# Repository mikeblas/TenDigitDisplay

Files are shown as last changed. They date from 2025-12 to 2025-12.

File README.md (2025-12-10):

Here is a project I made in the summer of 2025.

On a driving trip from Chicago back home to Seattle, I discovered [American Science and Surplus](https://sciplus.com/). Their store in Geneva, Illinois has lots of fun stuff, including some two-digit LED displays that I thought I could use to make a neat display.

The circuit in this project multiplexes the displays so they can be driven by the ESP-32. After a few iterations on the breadboard, I got boards done at [OSH Park](https://oshpark.com/) and soldered them up with through-hole parts that I mostly had in my inventory.

The web server on the ESP-32 has two endpoints: one takes a ten-digit hex string, which is a bitmap of the segments to illuminate on the display. The other takes a string of numbers to display -- they're converted from ASCII to their seven-segment representation.

I want to use the project to display some stock prices as they change. Since there's just seven segments, it's a bit crude, but something like "183.78d 1.19" means that the issue I'm tracking is at $183.78 per share, down (for "d") $1.19 per share since the last close.

Right now, all the smarts are in a Python scripts that run on a desktop computer. That script pokes at those endpoints and the ESP-32 just scans the multiplexed displays to show the last thing it was told. Eventually, the device could be standalone, though that comes with a few problems that I'll need to sort out.

Things to do:

* Make the Python script support multiple devices
* Show the DHCP-assigned IP address of the ESP-32 on the LEDs at startup
* Have the ESP-32 beacon a UDP message for automatic discovery by client scripts
* Smarter endpoints: accept characters and decimal points, for example
* Use the on-board LED to indicate stale data -- if no client has made an update in some time

And probably a few more things. But I'm also thinking about 16-segment display with 2 rows of 20 characters for a bit more fidelity ...

This repo contains these directories:

* `assets`: some pictures for the readme
* `TenDigitPCB`: a KiCAD project (including shape and footprint files) for the PCB and its components
* `TenDigitsIDF`: Visual Studio Code project for the ESP-32 IDF to implement the web server and multiplexing
* `TenDigitQuoter`: A Python project (for PyCharm) that shows quotes for a stock from the Yahoo! Finance API

Here are some pictures:

Front view of populated PCB

Reverse view of bare PCB

Quote being displayed

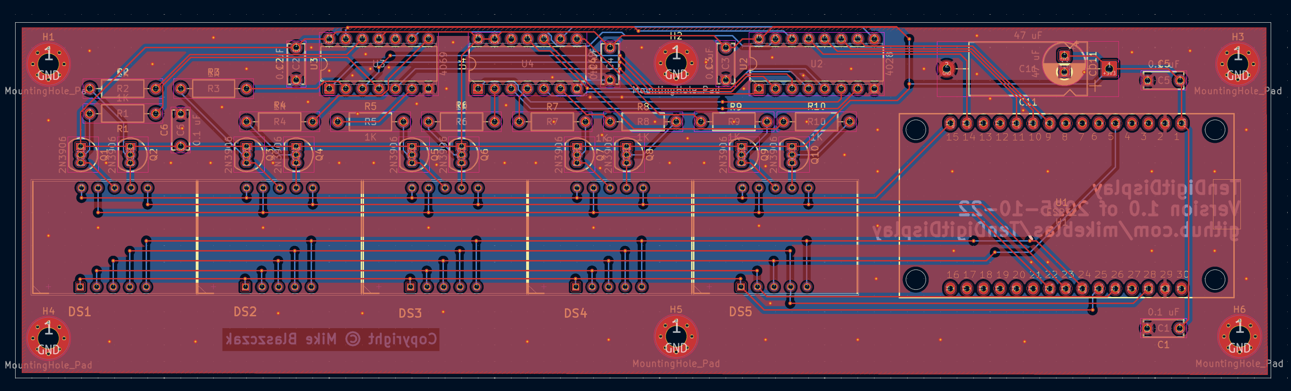
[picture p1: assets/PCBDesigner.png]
PCB in KiCAD designer


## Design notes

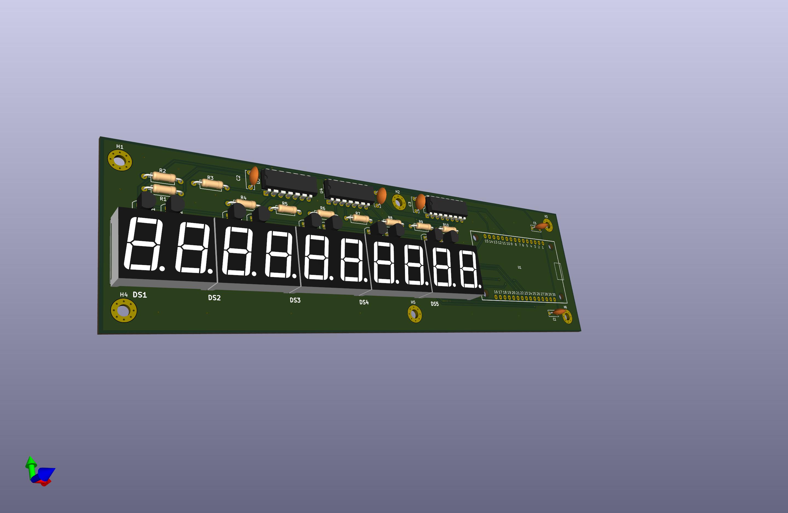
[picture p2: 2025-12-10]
TenDigitPCB/TenDigitPCB.jpg

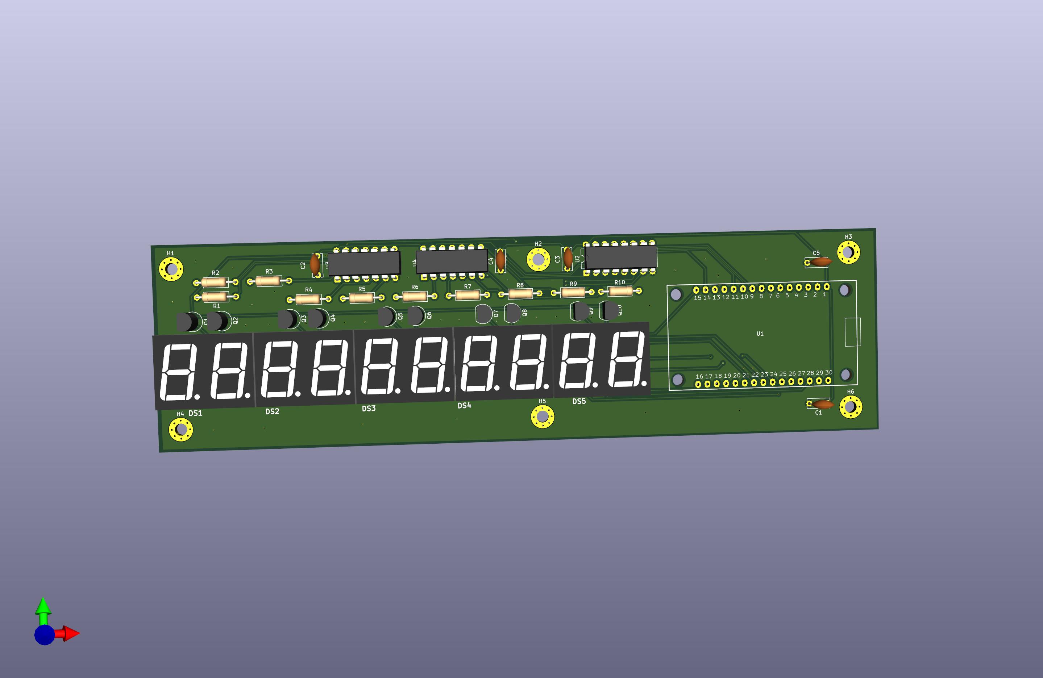
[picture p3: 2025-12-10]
TenDigitPCB/TenDigitPCB2.jpg

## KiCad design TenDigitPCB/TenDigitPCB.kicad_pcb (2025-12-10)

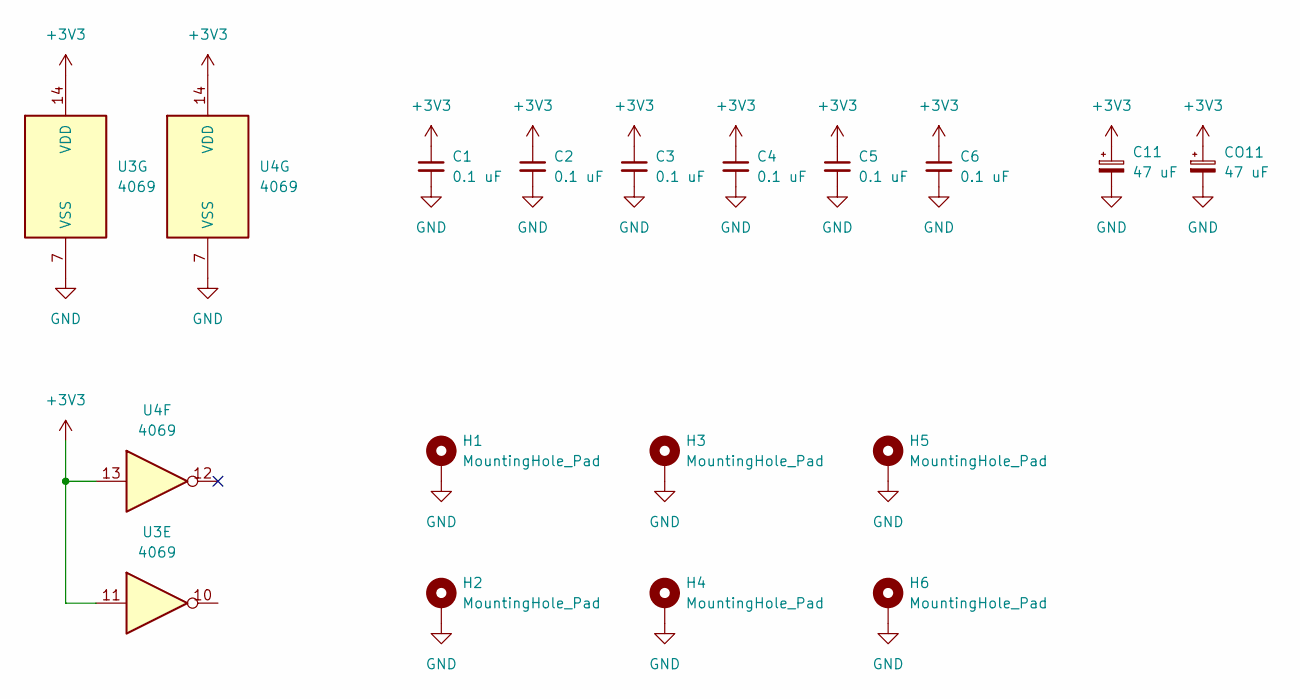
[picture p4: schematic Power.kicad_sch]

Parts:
C1, C2, C3, C4, C5, C6: 0.1 uF; C_Disc_D6.0mm_W2.5mm_P5.00mm
C11: 47 uF; CP_Axial_L18.0mm_D8.0mm_P25.00mm_Horizontal
CO11: 47 uF; CP_Radial_D6.3mm_P2.50mm
H1, H2, H3, H4, H5, H6: MountingHole_Pad; MountingHole_3.2mm_M3_Pad_Via
U3, U4: 4069; DIP-14_W7.62mm

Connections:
+3V3: C1.1, C2.1, C3.1, C4.1, C5.1, C6.1, C11.1, CO11.1, U3.11, U3.14 (VDD), U4.13, U4.14 (VDD); also elsewhere on the board
GND: C1.2, C2.2, C3.2, C4.2, C5.2, C6.2, C11.2, CO11.2, H1.1, H2.1, H3.1, H4.1, H5.1, H6.1, U3.7 (VSS), U4.7 (VSS); also elsewhere on the board

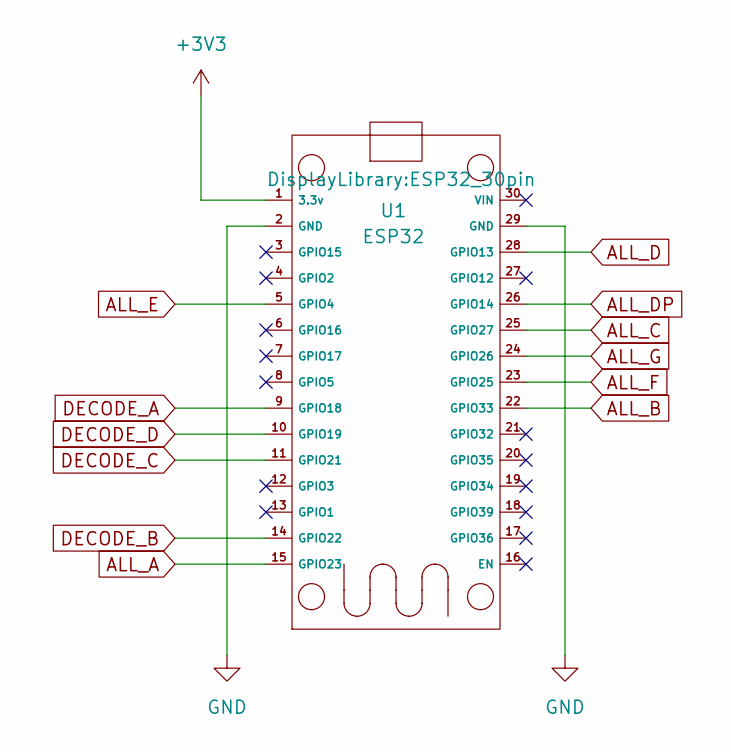
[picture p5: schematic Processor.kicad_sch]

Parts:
U1: ESP32; ESP32_30pin

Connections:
+3V3: U1.1 (3.3v); also elsewhere on the board
ALL_A: U1.15 (GPIO23); also elsewhere on the board
ALL_B: U1.22 (GPIO33); also elsewhere on the board
ALL_C: U1.25 (GPIO27); also elsewhere on the board
ALL_D: U1.28 (GPIO13); also elsewhere on the board
ALL_DP: U1.26 (GPIO14); also elsewhere on the board
ALL_E: U1.5 (GPIO4); also elsewhere on the board
ALL_F: U1.23 (GPIO25); also elsewhere on the board
ALL_G: U1.24 (GPIO26); also elsewhere on the board
DECODE_A: U1.9 (GPIO18); also elsewhere on the board
DECODE_B: U1.14 (GPIO22); also elsewhere on the board
DECODE_C: U1.11 (GPIO21); also elsewhere on the board
DECODE_D: U1.10 (GPIO19); also elsewhere on the board
GND: U1.2 (GND), U1.29 (GND); also elsewhere on the board

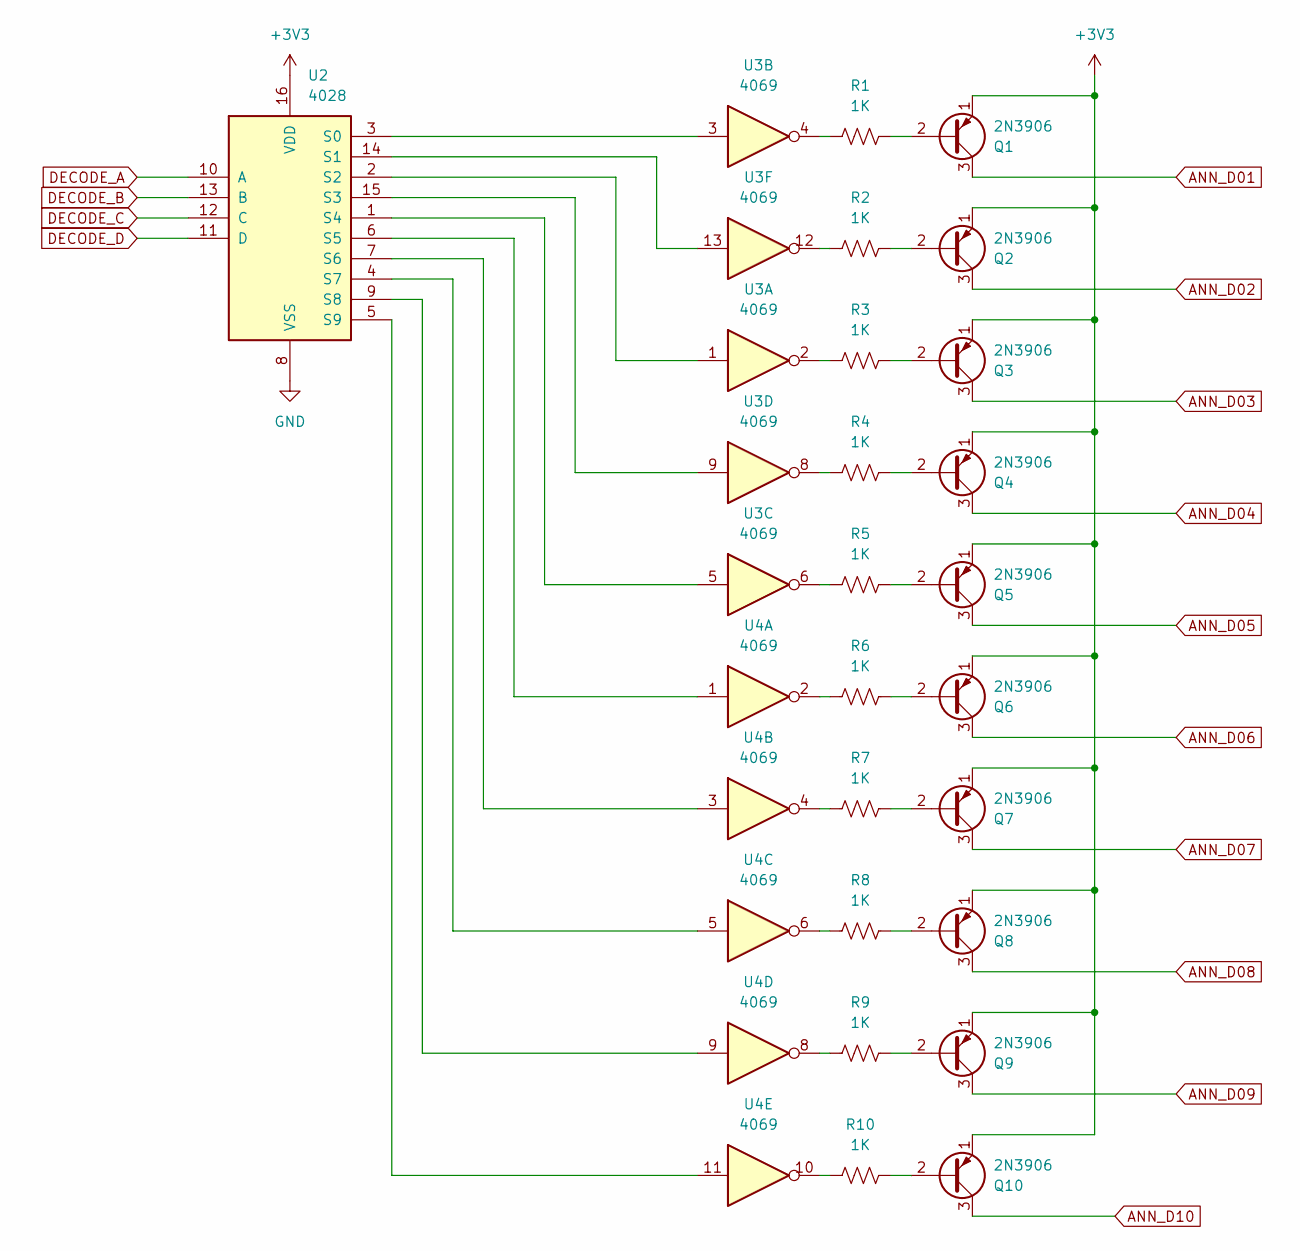
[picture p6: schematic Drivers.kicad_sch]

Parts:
Q1, Q2, Q3, Q4, Q5, Q6, Q7, Q8, Q9, Q10: 2N3906; TO-92_Inline
R1, R2, R3, R4, R5, R6, R7, R8, R9, R10: 1K; R_Axial_DIN0207_L6.3mm_D2.5mm_P10.16mm_Horizontal
U2: 4028; DIP-16_W7.62mm
U3, U4: 4069; DIP-14_W7.62mm

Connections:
+3V3: Q1.1 (E), Q2.1 (E), Q3.1 (E), Q4.1 (E), Q5.1 (E), Q6.1 (E), Q7.1 (E), Q8.1 (E), Q9.1 (E), Q10.1 (E), U2.16 (VDD); also elsewhere on the board
ANN_D01: Q1.3 (C); also elsewhere on the board
ANN_D02: Q2.3 (C); also elsewhere on the board
ANN_D03: Q3.3 (C); also elsewhere on the board
ANN_D04: Q4.3 (C); also elsewhere on the board
ANN_D05: Q5.3 (C); also elsewhere on the board
ANN_D06: Q6.3 (C); also elsewhere on the board
ANN_D07: Q7.3 (C); also elsewhere on the board
ANN_D08: Q8.3 (C); also elsewhere on the board
ANN_D09: Q9.3 (C); also elsewhere on the board
ANN_D10: Q10.3 (C); also elsewhere on the board
DECODE_A: U2.10 (A); also elsewhere on the board
DECODE_B: U2.13 (B); also elsewhere on the board
DECODE_C: U2.12 (C); also elsewhere on the board
DECODE_D: U2.11 (D); also elsewhere on the board
GND: U2.8 (VSS); also elsewhere on the board
unnamed: Q1.2 (B), R1.2
unnamed: Q2.2 (B), R2.2
unnamed: Q3.2 (B), R3.2
unnamed: Q4.2 (B), R4.2
unnamed: Q5.2 (B), R5.2
unnamed: Q6.2 (B), R6.2
unnamed: Q7.2 (B), R7.2
unnamed: Q8.2 (B), R8.2
unnamed: Q9.2 (B), R9.2
unnamed: Q10.2 (B), R10.2
unnamed: R1.1, U3.4
unnamed: R2.1, U3.12
unnamed: R3.1, U3.2
unnamed: R4.1, U3.8
unnamed: R5.1, U3.6
unnamed: R6.1, U4.2
unnamed: R7.1, U4.4
unnamed: R8.1, U4.6
unnamed: R9.1, U4.8
unnamed: R10.1, U4.10
unnamed: U2.3 (S0), U3.3
unnamed: U2.14 (S1), U3.13
unnamed: U2.2 (S2), U3.1
unnamed: U2.15 (S3), U3.9
unnamed: U2.1 (S4), U3.5
unnamed: U2.6 (S5), U4.1
unnamed: U2.7 (S6), U4.3
unnamed: U2.4 (S7), U4.5
unnamed: U2.9 (S8), U4.9
unnamed: U2.5 (S9), U4.11

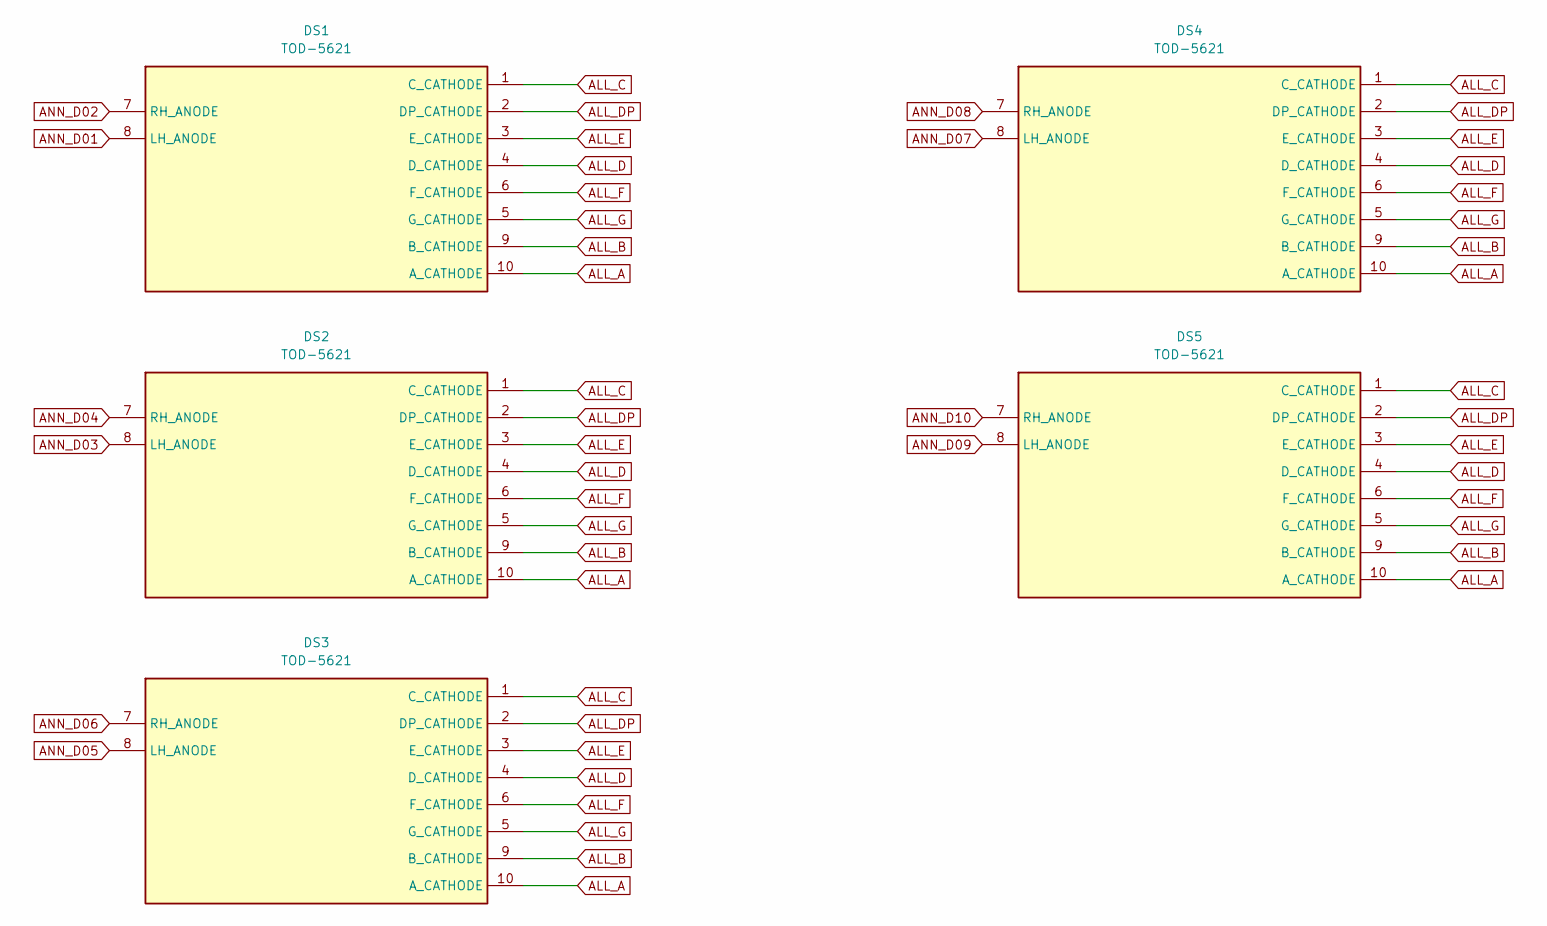
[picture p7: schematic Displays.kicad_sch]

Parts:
DS1, DS2, DS3, DS4, DS5: TOD-5621; Mouser Part Number 630-HDSP-K511

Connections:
ALL_A: DS1.10 (A_CATHODE), DS2.10 (A_CATHODE), DS3.10 (A_CATHODE), DS4.10 (A_CATHODE), DS5.10 (A_CATHODE); also elsewhere on the board
ALL_B: DS1.9 (B_CATHODE), DS2.9 (B_CATHODE), DS3.9 (B_CATHODE), DS4.9 (B_CATHODE), DS5.9 (B_CATHODE); also elsewhere on the board
ALL_C: DS1.1 (C_CATHODE), DS2.1 (C_CATHODE), DS3.1 (C_CATHODE), DS4.1 (C_CATHODE), DS5.1 (C_CATHODE); also elsewhere on the board
ALL_D: DS1.4 (D_CATHODE), DS2.4 (D_CATHODE), DS3.4 (D_CATHODE), DS4.4 (D_CATHODE), DS5.4 (D_CATHODE); also elsewhere on the board
ALL_DP: DS1.2 (DP_CATHODE), DS2.2 (DP_CATHODE), DS3.2 (DP_CATHODE), DS4.2 (DP_CATHODE), DS5.2 (DP_CATHODE); also elsewhere on the board
ALL_E: DS1.3 (E_CATHODE), DS2.3 (E_CATHODE), DS3.3 (E_CATHODE), DS4.3 (E_CATHODE), DS5.3 (E_CATHODE); also elsewhere on the board
ALL_F: DS1.6 (F_CATHODE), DS2.6 (F_CATHODE), DS3.6 (F_CATHODE), DS4.6 (F_CATHODE), DS5.6 (F_CATHODE); also elsewhere on the board
ALL_G: DS1.5 (G_CATHODE), DS2.5 (G_CATHODE), DS3.5 (G_CATHODE), DS4.5 (G_CATHODE), DS5.5 (G_CATHODE); also elsewhere on the board
ANN_D01: DS1.8 (LH_ANODE); also elsewhere on the board
ANN_D02: DS1.7 (RH_ANODE); also elsewhere on the board
ANN_D03: DS2.8 (LH_ANODE); also elsewhere on the board
ANN_D04: DS2.7 (RH_ANODE); also elsewhere on the board
ANN_D05: DS3.8 (LH_ANODE); also elsewhere on the board
ANN_D06: DS3.7 (RH_ANODE); also elsewhere on the board
ANN_D07: DS4.8 (LH_ANODE); also elsewhere on the board
ANN_D08: DS4.7 (RH_ANODE); also elsewhere on the board
ANN_D09: DS5.8 (LH_ANODE); also elsewhere on the board
ANN_D10: DS5.7 (RH_ANODE); also elsewhere on the board

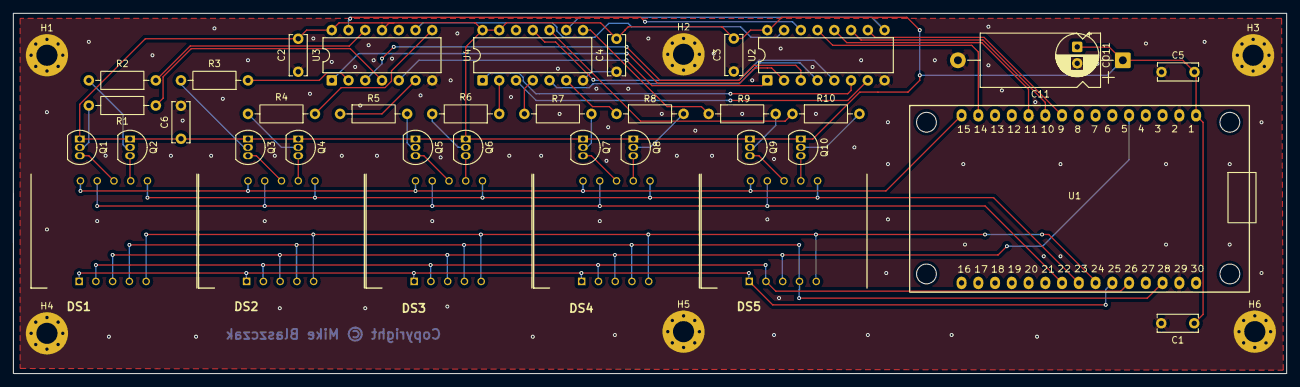
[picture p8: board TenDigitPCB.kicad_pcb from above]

Board: 2 copper layers, 193.1 x 54.6 mm, 43 parts (0 on the bottom side), 54 nets.

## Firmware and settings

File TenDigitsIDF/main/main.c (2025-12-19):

// https://medium.com/@fatehsali517/how-to-connect-esp32-to-wifi-using-esp-idf-iot-development-framework-d798dc89f0d6

// https://developer.espressif.com/blog/getting-started-with-wifi-on-esp-idf/

// https://developer.espressif.com/blog/getting-started-with-wifi-on-esp-idf/

// https://stackoverflow.com/questions/78808438/esp-idf-wifi-always-fails-to-connect-the-first-time

#include <stdio.h>

#include "sdkconfig.h"
#include "freertos/FreeRTOS.h"
#include "freertos/task.h"
#include "esp_chip_info.h"
#include "esp_flash.h"
#include "esp_system.h"
#include "esp_timer.h"
#include "esp_log.h"
#include "esp_sleep.h"
#include "esp_task_wdt.h"

#include "driver/gpio.h"
#include "hal/gpio_ll.h"

#include <esp_http_server.h>
#include <esp_event.h>
#include <esp_log.h>

#include "globals.h"

#include "display.h"
#include "nvs.h"
#include "wifi.h"
#include "web.h"

// wifi structure:
//      https://developer.espressif.com/blog/getting-started-with-wifi-on-esp-idf/

const char* LOG_TAG = "TenDigits";

const char *pass = "girlmoose";
const char *ssid = "blaszczak2g";





/*
    Prints a sign on message about the satus of the device
*/
static void start_up_message(void)
{
    // Print chip information
    esp_chip_info_t chip_info;
    uint32_t flash_size;
    esp_chip_info(&chip_info);
    ESP_LOGI(LOG_TAG, "This is %s chip with %d CPU core(s), %s%s%s%s",
           CONFIG_IDF_TARGET,
           chip_info.cores,
           (chip_info.features & CHIP_FEATURE_WIFI_BGN) ? "WiFi/" : "",
           (chip_info.features & CHIP_FEATURE_BT) ? "BT" : "",
           (chip_info.features & CHIP_FEATURE_BLE) ? "BLE" : "",
           (chip_info.features & CHIP_FEATURE_IEEE802154) ? ", 802.15.4 (Zigbee/Thread)" : "");

    unsigned major_rev = chip_info.revision / 100;
    unsigned minor_rev = chip_info.revision % 100;
    ESP_LOGI(LOG_TAG, "silicon revision v%d.%d", major_rev, minor_rev);

    if (esp_flash_get_size(NULL, &flash_size) != ESP_OK)
    {
        ESP_LOGW(LOG_TAG, "Get flash size failed");
    }
    else
    {
        ESP_LOGI(LOG_TAG, "%" PRIu32 "MB %s flash\n", flash_size / (uint32_t)(1024 * 1024),
               (chip_info.features & CHIP_FEATURE_EMB_FLASH) ? "embedded" : "external");
    }

    ESP_LOGI(LOG_TAG, "Minimum free heap size: %" PRIu32 " bytes\n", esp_get_minimum_free_heap_size());
}


/*
    toggles the state of the built-in LED
*/
static /* IRAM_ATTR */ void flash_builtin_callback(void* arg)
{
    static bool builtin_state = true;

    builtin_state = !builtin_state;
    gpio_set_level(LED_BUILTIN, builtin_state);

    if (++dpPlace > 9)
        dpPlace = 0;
}


/*
    Sets up a periodic timer that will flash the builtin LED
*/
static void start_builtin_timer(void)
{
    const esp_timer_create_args_t periodic_timer_args = {
        .callback = &flash_builtin_callback,
        .name = "builtin",
        .dispatch_method = ESP_TIMER_ISR
    };
    
    esp_timer_handle_t periodic_timer;
    ESP_ERROR_CHECK(esp_timer_create(&periodic_timer_args, &periodic_timer));
    // value in microseconds
    ESP_ERROR_CHECK(esp_timer_start_periodic(periodic_timer, 500333));

    ESP_LOGI(LOG_TAG, "Started timer for builtin flash, time since boot: %lld us", esp_timer_get_time());
}


/*
    Increments our count, then breaks it into individual digits
    for display by the scanner.
*/
static /* IRAM_ATTR */ void counter_callback(void* arg)
{
    if (++counter > 9999999999)
    {
        int64_t time_since_boot = esp_timer_get_time();
        ESP_LOGI(LOG_TAG, "Periodic timer: time since boot: %lld us, counter wrapped", time_since_boot);
        counter = 0;
    }

    counterDigits[9] = counter % 10;
    counterDigits[8] = (counter / 10) % 10;
    counterDigits[7] = (counter / 100) % 10;
    counterDigits[6] = (counter / 1000) % 10;
    counterDigits[5] = (counter / 10000) % 10;
    counterDigits[4] = (counter / 100000) % 10;
    counterDigits[3] = (counter / 1000000) % 10;
    counterDigits[2] = (counter / 10000000) % 10;
    counterDigits[1] = (counter / 100000000) % 10;
    counterDigits[0] = (counter / 1000000000) % 10;

    counter_to_segments();
}


/*
    Sets up a periodic timer that counts, then builds the digits array
*/
static void start_count_timer(void)
{
    const esp_timer_create_args_t periodic_timer_args = {
        .callback = &counter_callback,
        .name = "counter",
        .dispatch_method = ESP_TIMER_ISR
    };
    
    esp_timer_handle_t periodic_timer;
    ESP_ERROR_CHECK(esp_timer_create(&periodic_timer_args, &periodic_timer));
    // value in microseconds
    ESP_ERROR_CHECK(esp_timer_start_periodic(periodic_timer, 15000));

    ESP_LOGI(LOG_TAG, "Started timer for counter, time since boot: %lld us", esp_timer_get_time());
}


void scan_task(void *pvParameters)
{
    TickType_t xLastWakeTime = xTaskGetTickCount();

    while (true)
    {
        static uint8_t working_digit = 0;

        // turn segments off because switching isn't atomic
        writeSegments(0);

        // turn on this digit
        activateDecoderChannel(working_digit);

        // and write its segments
        // writeSegments(digitToSegments[counterDigits[working_digit]]);
        writeSegments(segmentValues[working_digit]);

        // manage the DP
        // gpio_set_level(SEGMENT_DP, (working_digit == dpPlace) ? LOW : HIGH);

        // and think about the next digit
        if (++working_digit > 9)
        {
            working_digit = 0;
        }

        // vTaskDelayUntil(&xLastWakeTime, pdMS_TO_TICKS(1));
        // vTaskDelayUntil(&xLastWakeTime, 1);
        vTaskDelay(pdMS_TO_TICKS(5));
        // vTaskDelay(1);
        taskYIELD();
        // esp_task_wdt_reset();
    }
}


static void start_scan_task(void)
{
    // this disables the watchdog timer, which gives errors
    // because the idle task on the same CPU as the scan task won't run enough
    esp_task_wdt_delete(xTaskGetIdleTaskHandleForCPU(APP_CPU_NUM));

    xTaskCreatePinnedToCore(
        scan_task,      // Task function
        "ScanTask",     // Task name
        4096,           // Stack size in bytes
        NULL,           // Parameters to pass to the task
        tskIDLE_PRIORITY + 2,              // Task priority
        NULL,           // Task handle (not needed for this example)
        APP_CPU_NUM     // Pin to APP_CPU (Core 1)
    );
}


/*
    Scan the digits. This places the content of counterDigits[] into each
    digit by translating the byte value into segments, and poking the segments.
    Each call does one digit, working thruogh the nine.
*/
static /* IRAM_ATTR */ void scan_callback(void* arg)
{
    static uint8_t working_digit = 0;

    // turn segments off because switching isn't atomic
    // writeSegments(0);

    // turn on this digit
    activateDecoderChannel(working_digit);

    // and write its segments
    // writeSegments(digitToSegments[counterDigits[working_digit]]);
    writeSegments(segmentValues[working_digit]);

    // manage the DP
    setDP((working_digit == dpPlace) ? LOW : HIGH);

    // and think about the next digit
    if (++working_digit > 9)
        working_digit = 0;

    // ESP_LOGI(LOG_TAG, "workingDigit %d, counter %d, digit is %d", workingDigit, counter, counterDigits[workingDigit]);
}


/*
    Sets up a periodic timer that will flash the builtin LED
*/
static void start_scan_timer(void)
{
    const esp_timer_create_args_t periodic_timer_args = {
        .callback = &scan_callback,
        .name = "digitscan",
        .dispatch_method = ESP_TIMER_ISR
    };
    
    esp_timer_handle_t periodic_timer;
    ESP_ERROR_CHECK(esp_timer_create(&periodic_timer_args, &periodic_timer));
    // value in microseconds
    ESP_ERROR_CHECK(esp_timer_start_periodic(periodic_timer, 1000));

    ESP_LOGI(LOG_TAG, "Started timer for digit scan, time since boot: %lld us", esp_timer_get_time());
}


/*
    Called when the WiFi interface receives an address. When called, we know my_ip[] is valid.

    Here, we will display our IP address -- starting from the right digits and truncating at the left
    if we have to. This gives a hint to the IP address at power-up.
*/
void wifi_address_handler(void)
{
    char address[50];
    int len = snprintf(address, sizeof(address), "%d.%d.%d.%d", my_ip[0], my_ip[1], my_ip[2], my_ip[3]);

    int8_t digit = 9;
    bool over = false;
    bool nextDot = false;
    char *walker = address + len - 1;
    while (digit >= 0)
    {
        if (over)
        {
            // out of characters? fill with blank segments
            segmentValues[digit] = 0;
            digit--;
        }
        else
        {
            if (walker < address)
            {
                // out of characters?
                over = true;
            }
            else
            {
                // got a dot? then we'll want that for the next character
                if (*walker == '.')
                {
                    nextDot = true;
                    walker--;
                }
                else
                {
                    // figure out this numeral;
                    // if it's valid, make segments of it
                    int8_t dig = (*walker) - '0';
                    if (dig > 9 || dig < 0)
                        segmentValues[digit] = 0;
                    else
                        segmentValues[digit] = digitToSegments[dig];

                    // were we working a dot?
                    if (nextDot)
                        set_decimal_point(digit);

                    // ESP_LOGI(LOG_TAG, "Digit %d is set to 0x%2.2X", digit, segmentValues[digit]);
                    nextDot = false;
                    walker--;
                    digit--;
                }
            }
        }
    }
}


/*
    here's our main entry point.

    Get the I/O initialized, set a timer, and that's that.
    All the work is in the timer handler.
*/
void app_main(void)
{
    ESP_LOGI(LOG_TAG, "**************");
    ESP_LOGI(LOG_TAG, " TenDigitsIDF");
    ESP_LOGI(LOG_TAG, "**************");
    start_up_message();

    setup_pins();

    initialize_nvs();

    // set a callback to hear abou a WiFi address being assigned
    on_wifi_address = &wifi_address_handler;

    wifi_connection();

    start_webserver();

    start_builtin_timer();

    // start_scan_timer();

    start_scan_task();

    // start_count_timer();

    ESP_LOGI(LOG_TAG, "main is done, time since boot: %lld us", esp_timer_get_time());
}

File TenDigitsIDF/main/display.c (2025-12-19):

#include "sdkconfig.h"
#include "freertos/FreeRTOS.h"
#include "freertos/task.h"

#include "esp_flash.h"

#include "driver/gpio.h"
#include "hal/gpio_ll.h"


#include "globals.h"



MY_DRAM_ATTR uint8_t dpPlace = 0;

MY_DRAM_ATTR uint64_t counter = 0;
MY_DRAM_ATTR uint8_t counterDigits[10];

// the scanner writes these segments each scan
MY_DRAM_ATTR uint8_t segmentValues[10];


// segments are active low
static const uint8_t SEGMENT_A = 23; // was 32
static const uint8_t SEGMENT_B = 33;
static const uint8_t SEGMENT_C = 27;
static const uint8_t SEGMENT_D = 13;
static const uint8_t SEGMENT_E = 4;
static const uint8_t SEGMENT_F = 25;
static const uint8_t SEGMENT_G = 26;
static const uint8_t SEGMENT_DP = 14;

// these go to CD4028 decoder
static const uint8_t DECODE_A = 18;
static const uint8_t DECODE_B = 22;
static const uint8_t DECODE_C = 21;
static const uint8_t DECODE_D = 19;

#define MY_DRAM_ATTR DRAM_ATTR
// #define MY_DRAM_ATTR 

/* const */ MY_DRAM_ATTR uint8_t digitToSegments[] =
{
    0b00111111,   // digit 0
    0b00000110,   // digit 1
    0b01011011,   // digit 2
    0b01001111,   // digit 3
    0b01100110,   // digit 4
    0b01101101,   // digit 5
    0b01111101,   // digit 6
    0b00000111,   // digit 7
    0b01111111,   // digit 8
    0b01100111,   // digit 9
    0b01110111,   // digit A
    0b01111100,   // digit b
    0b00111001,   // digit C
    0b01011110,   // digit d
    0b01111001,   // digit E
    0b01110001,   // digit F
};

static /* const */ MY_DRAM_ATTR uint8_t segmentMap[] =
{
    SEGMENT_A,
    SEGMENT_B,
    SEGMENT_C,
    SEGMENT_D,
    SEGMENT_E,
    SEGMENT_F,
    SEGMENT_G,
    SEGMENT_DP
};

static /* const */ MY_DRAM_ATTR uint8_t decodeMap[] =
{
    DECODE_A,
    DECODE_B,
    DECODE_C,
    DECODE_D
};

/*
    activate the given common anode on the given digit
    n is [0..9], and 0 is the left-most digit
*/
/* IRAM_ATTR */ void activateDecoderChannel(uint8_t n)
{
#if 0
    gpio_set_level(DECODE_A, (n & 1) == 0 ? LOW : HIGH);
    gpio_set_level(DECODE_B, (n & 2) == 0 ? LOW : HIGH);
    gpio_set_level(DECODE_C, (n & 4) == 0 ? LOW : HIGH);
    gpio_set_level(DECODE_D, (n & 8) == 0 ? LOW : HIGH);
#else

    uint32_t sets = 0;
    uint32_t clears = 0;

    uint8_t mask = 1;
    for (uint8_t i = 0; i < 4; i++, mask <<= 1)
    {
        if ((n & mask) == 0)
            clears |= (uint32_t)1 << decodeMap[i];
        else
            sets |= (uint32_t)1 << decodeMap[i];
        // ESP_LOGI(LOG_TAG, "n = %d, mask = %d, sets = %ld and clears = %ld", i, mask, sets, clears);
    }

    // ESP_LOGI(LOG_TAG, "got %d, sets = %ld and clears = %ld", (int) n, sets, clears);

    GPIO.out_w1ts = sets;
    GPIO.out_w1tc = clears;

#endif
}


/*
    Write the given segment bitmask to the segment output pins, 
    observing active low logic for the common anode part.

    The segments parameter has a bit on for a segment to be lit. 
    Segment A is the LSB, and the DP is the MSB. Bits in the parameter
    are set to turn the corresponding segment on.
*/
/* IRAM_ATTR */ void writeSegments(uint8_t segments)
{
#if 0
    uint8_t mask = 1;
    for (int x = 0; x < 8; x++)
    {
        gpio_set_level(segmentMap[x], ((segments & mask) == 0) ? HIGH : LOW);
        mask <<= 1;
    }
#else
    uint32_t sets = 0;
    uint32_t clears = 0;

    uint32_t sets32 = 0;
    uint32_t clears32 = 0;

    uint8_t mask = 1;
    for (uint8_t i = 0; i < 8; i++, mask <<= 1)
    {
        // note this implements active low: a 1 in the bitmask will clear the GPIO line
        if ((segments & mask) != 0)
        {
            if (segmentMap[i] < 32)
                clears |= (uint32_t)1U << segmentMap[i];
            else
                clears32 |= (uint32_t)1U << (segmentMap[i] - 32);
        }
        else
        {
            if (segmentMap[i] < 32)
                sets |= (uint32_t)1U << segmentMap[i];
            else
                sets32 |= (uint32_t)1U << (segmentMap[i] - 32);
        }
    }

    GPIO.out_w1ts = sets;
    GPIO.out_w1tc = clears;

    GPIO.out1_w1ts.val = sets32;
    GPIO.out1_w1tc.val = clears32;
#endif
}


/*
    turn on the DP in the given digit
*/
void set_decimal_point(uint8_t digit)
{
    segmentValues[digit] |= 0x80;
}


/*
    turn off the DP in the given digit
*/
void clear_decimal_point(uint8_t digit)
{
    segmentValues[digit] &= 0x80;
}


/*
    clear the given GPIO pin, then set it up as an output
*/
static void set_output(gpio_num_t pin)
{
    gpio_reset_pin(pin);
    gpio_set_direction(pin, GPIO_MODE_OUTPUT);
}


/*
    sets up our GPIO pins during initialization
*/
void setup_pins(void)
{
    // all the segments are outputs
    for (int n = 0; n < _countof(segmentMap); n++)
        set_output(segmentMap[n]);

    // built-in is an output
    set_output(LED_BUILTIN);

    // drives are outputs
    set_output(DECODE_A);
    set_output(DECODE_B);
    set_output(DECODE_C);
    set_output(DECODE_D);
}


/*
void setDP(bool on)
{
    gpio_set_level(SEGMENT_DP, on ? LOW : HIGH);
}
*/


void counter_to_segments(void)
{
    for (int n = 0; n < 10; n++)
    {
        segmentValues[n] = digitToSegments[counterDigits[n]];
    }
}

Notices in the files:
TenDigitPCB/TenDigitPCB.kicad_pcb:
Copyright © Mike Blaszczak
